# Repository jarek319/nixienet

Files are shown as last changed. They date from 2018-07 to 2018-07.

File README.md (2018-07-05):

# nixienet
Connecting 1960's tube tech to 2010's Wifi chips!

This Wifi gadget connects to time and weather forecast servers and uses Nixie tubes to display the current time and upcoming weather.

It's one of the most full designs I've ever made, from insides to outsides. So fun :)

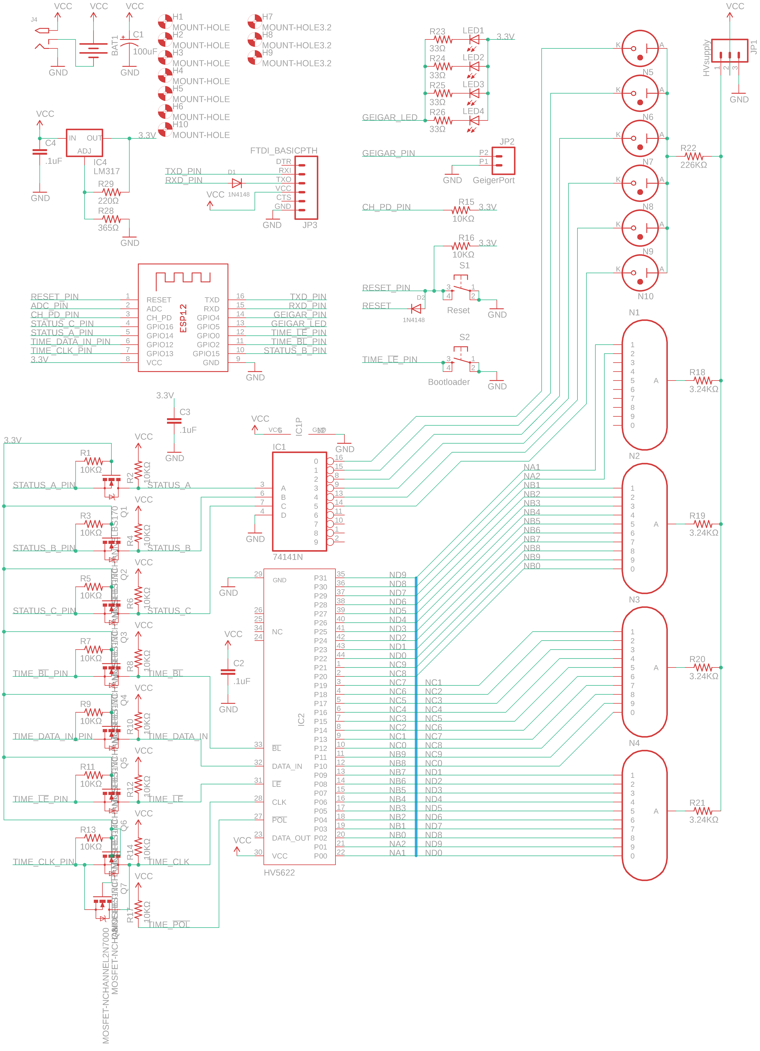
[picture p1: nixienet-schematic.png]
schematic

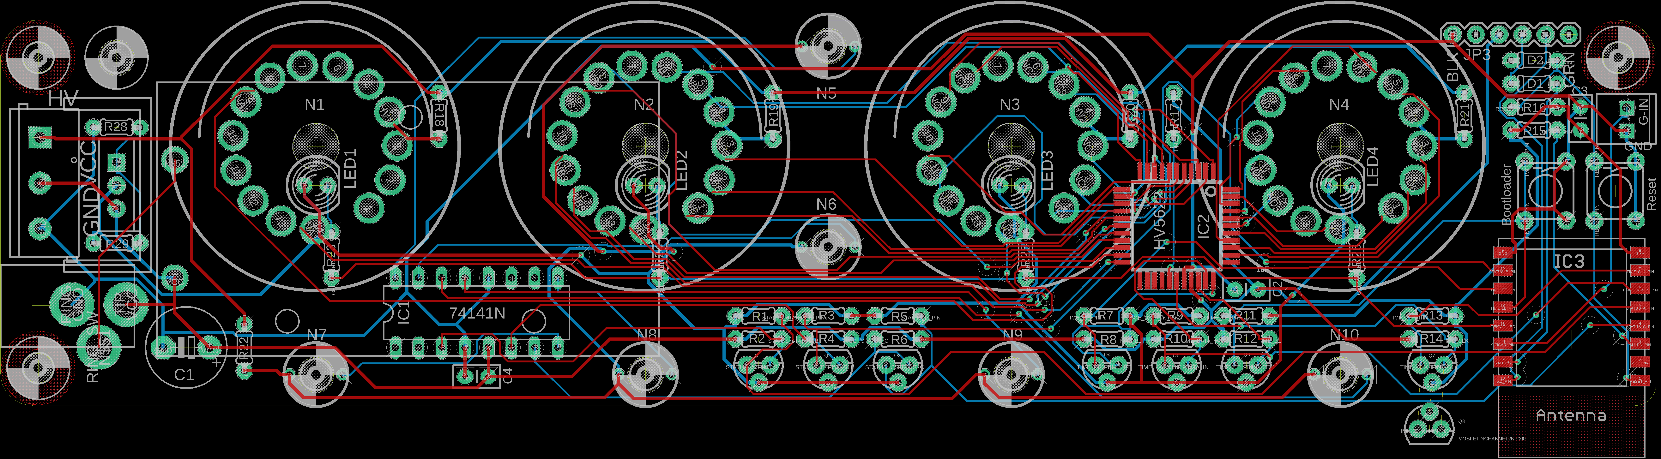
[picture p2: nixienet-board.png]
board

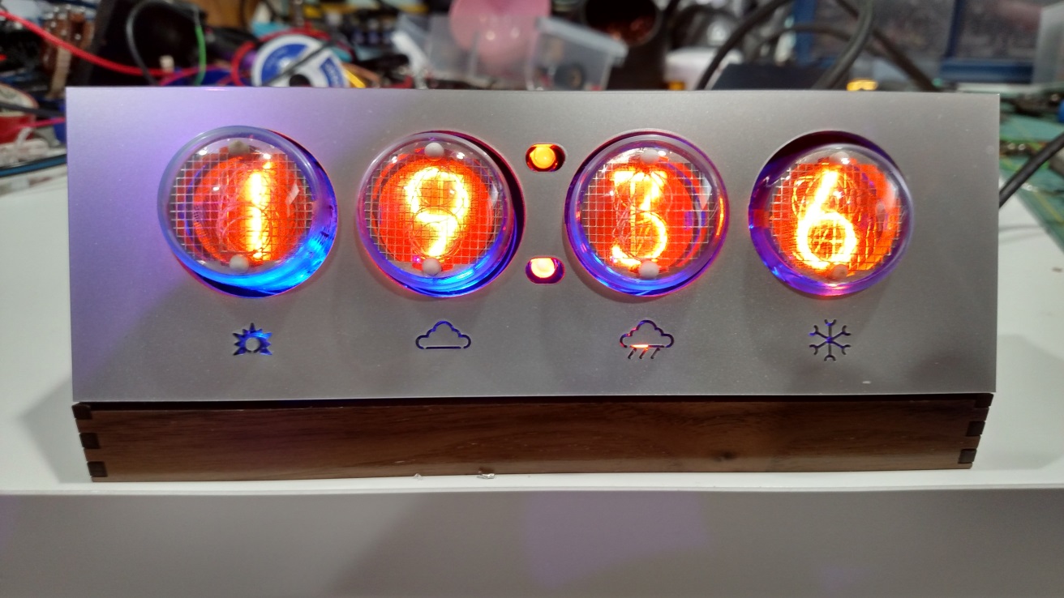
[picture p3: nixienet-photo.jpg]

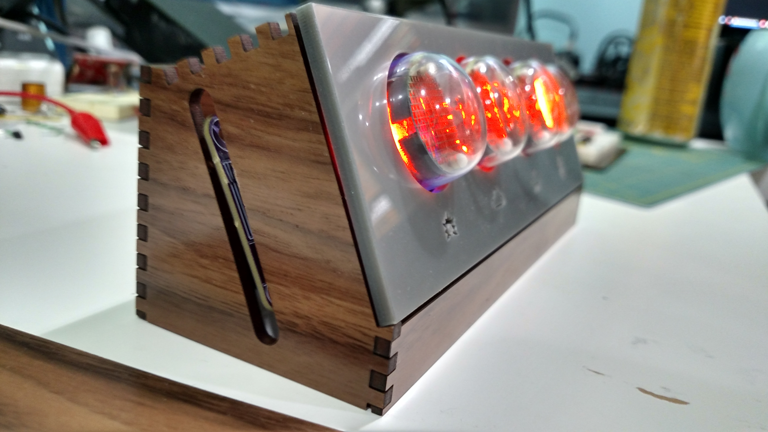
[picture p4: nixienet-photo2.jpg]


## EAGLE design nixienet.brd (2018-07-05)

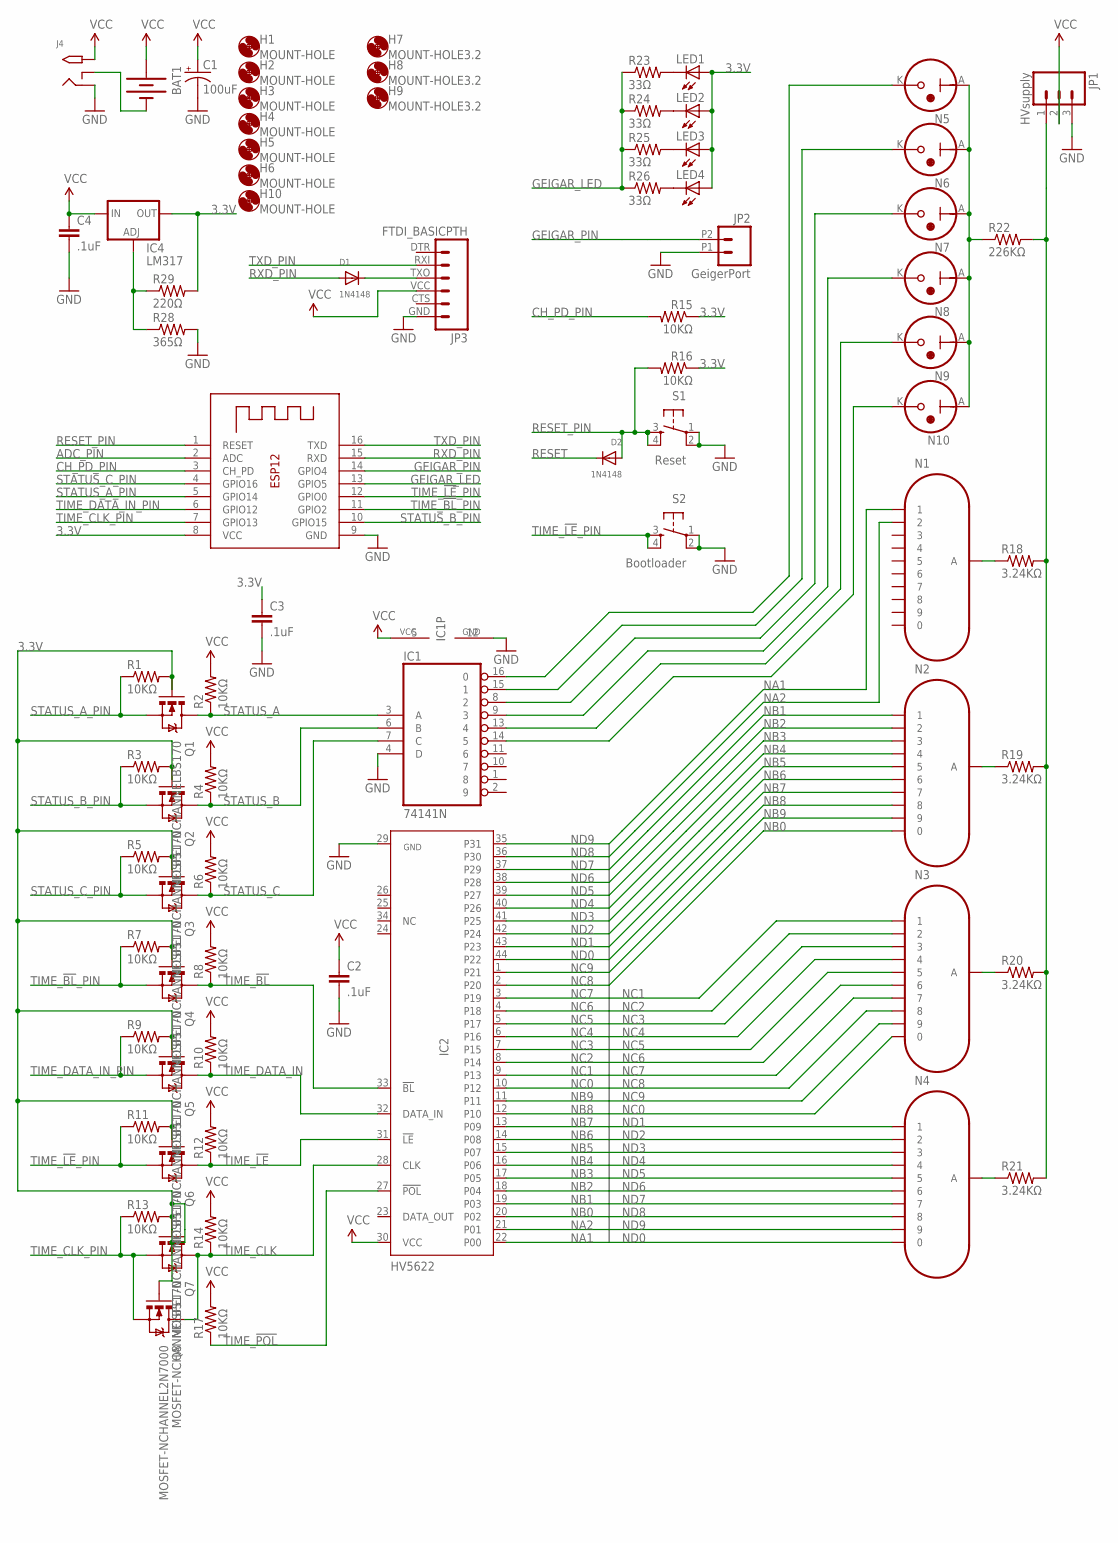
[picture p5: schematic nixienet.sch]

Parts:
BAT1: BATTERY9V; BATTCON_9V
C1: 100uF; E5-8,5
C2, C3, C4: .1uF; CAP-PTH-SMALLEZ
D1, D2: 1N4148
H1, H2, H3, H4, H5, H6, H10: MOUNT-HOLE; 3,2-DANGER
H7, H8, H9: MOUNT-HOLE3.2; 3,2
IC1: 74141N; DIL16
IC2: HV5622; QFP44
IC3: ESP-12
IC4: LM317; SPARKFUN-POWERIC_TO220-ADJ
J4: 2.1MMJACKTHM; PJ-102A
JP1: HVsupply; SCREWTERMINAL-5MM-3
JP2: GeigerPort; 1X02_2.54_SCREWTERM
JP3: FTDI_BASICPTH; FTDI_BASIC
LED1, LED2, LED3, LED4: LED5MM
N1: Hour1; IN-18
N2: Hour2; IN-18
N3: Minutes1; IN-18
N4: Minutes2; IN-18
N5: TopBulb; INS-1
N6: BottomBulb; INS-1
N7: SunnyBulb; INS-1
N8: CloudyBulb; INS-1
N9: RainyBulb; INS-1
N10: SnowyBulb; INS-1
Q1, Q2, Q3, Q4, Q5, Q6, Q7: MOSFET-NCHANNELBS170; TO-92
Q8: MOSFET-NCHANNEL2N7000; TO-92
R1, R2, R3, R4, R5, R6, R7, R8, R9, R10, R11, R12, R13, R14, R15, R16, R17: 10KΩ; 0204/5
R18, R19, R20, R21: 3.24KΩ; 0204/5
R22: 226KΩ; 0204/5
R23, R24, R25, R26: 33Ω; 0204/5
R28: 365Ω; 0204/5
R29: 220Ω; 0204/5
S1: Reset; TACTILE-PTH
S2: Bootloader; TACTILE-PTH

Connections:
3.3V: C3.1, IC3.8 (VCC), IC4.OUT, LED1.A, LED2.A, LED3.A, LED4.A, Q1.2 (G), Q2.2 (G), Q3.2 (G), Q4.2 (G), Q5.2 (G), Q6.2 (G), Q7.2 (G), Q8.2 (G), R1.2, R3.2, R5.2, R7.2, R9.2, R11.2, R13.2, R15.1, R16.1, R29.2
ADC_PIN: IC3.2 (ADC)
CH_PD_PIN: IC3.3 (CH_PD), R15.2
GEIGAR_LED: IC3.13 (GPIO5), R23.1, R24.1, R25.1, R26.1
GEIGAR_PIN: IC3.14 (GPIO4), JP2.P2 (2)
GND: C1.-, C2.2, C3.2, C4.2, IC1.4 (D), IC1.12 (GND), IC2.29 (GND), IC3.9 (GND), J4.RING, JP1.3, JP2.P1 (1), JP3.GND (6), R28.2, S1.1, S1.2, S2.1, S2.2
HV: JP1.1, R18.2, R19.2, R20.2, R21.2, R22.2
HV1: N1.4 (A), R18.1
HV2: N2.4 (A), R19.1
HV3: N3.4 (A), R20.1
HV4: N4.4 (A), R21.1
HVB: N5.A, N6.A, N7.A, N8.A, N9.A, N10.A, R22.1
unnamed: IC4.ADJ, R28.1, R29.1
unnamed: IC1.14 (5), N10.K
unnamed: IC1.13 (4), N9.K
unnamed: IC1.9 (3), N8.K
unnamed: IC1.8 (2), N7.K
unnamed: IC1.15 (1), N6.K
unnamed: IC1.16 (0), N5.K
unnamed: D1.K (C), JP3.TXO (3)
unnamed: BAT1.-, J4.RING_SW
unnamed: LED1.K (C), R23.2
unnamed: LED3.K (C), R25.2
unnamed: LED4.K (C), R26.2
unnamed: LED2.K (C), R24.2
NA1: IC2.22 (P00), N1.14 (1)
NA2: IC2.21 (P01), N1.9 (2)
NB0: IC2.20 (P02), N2.8 (0)
NB1: IC2.19 (P03), N2.14 (1)
NB2: IC2.18 (P04), N2.9 (2)
NB3: IC2.17 (P05), N2.11 (3)
NB4: IC2.16 (P06), N2.1 (4)
NB5: IC2.15 (P07), N2.12 (5)
NB6: IC2.14 (P08), N2.2 (6)
NB7: IC2.13 (P09), N2.6 (7)
NB8: IC2.12 (P10), N2.3 (8)
NB9: IC2.11, N2.5 (9)
NC0: IC2.10 (P12), N3.8 (0)
NC1: IC2.9 (P13), N3.14 (1)
NC2: IC2.8 (P14), N3.9 (2)
NC3: IC2.7 (P15), N3.11 (3)
NC4: IC2.6 (P16), N3.1 (4)
NC5: IC2.5 (P17), N3.12 (5)
NC6: IC2.4 (P18), N3.2 (6)
NC7: IC2.3 (P19), N3.6 (7)
NC8: IC2.2 (P20), N3.3 (8)
NC9: IC2.1 (P21), N3.5 (9)
ND0: IC2.44 (P22), N4.8 (0)
ND1: IC2.43 (P23), N4.14 (1)
ND2: IC2.42 (P24), N4.9 (2)
ND3: IC2.41 (P25), N4.11 (3)
ND4: IC2.40 (P26), N4.1 (4)
ND5: IC2.39 (P27), N4.12 (5)
ND6: IC2.38 (P28), N4.2 (6)
ND7: IC2.37 (P29), N4.6 (7)
ND8: IC2.36 (P30), N4.3 (8)
ND9: IC2.35 (P31), N4.5 (9)
RESET: D2.K (C)
RESET_PIN: D2.A, IC3.1 (RESET), R16.2, S1.3, S1.4
RXD_PIN: D1.A, IC3.15 (RXD)
STATUS_A: IC1.3 (A), Q1.1 (D), R2.1
STATUS_A_PIN: IC3.5 (GPIO14), Q1.3 (S), R1.1
STATUS_B: IC1.6 (B), Q2.1 (D), R4.1
STATUS_B_PIN: IC3.10 (GPIO15), Q2.3 (S), R3.1
STATUS_C: IC1.7 (C), Q3.1 (D), R6.1
STATUS_C_PIN: IC3.4 (GPIO16), Q3.3 (S), R5.1
TIME_!BL: IC2.33 (!BL), Q4.1 (D), R8.1
TIME_!BL!_PIN: IC3.11 (GPIO2), Q4.3 (S), R7.1
TIME_!LE: IC2.31 (!LE!), Q6.1 (D), R12.1
TIME_!LE!_PIN: IC3.12 (GPIO0), Q6.3 (S), R11.1, S2.3, S2.4
TIME_!POL: IC2.27 (!POL!), R17.1
TIME_CLK: IC2.28 (CLK), Q7.1 (D), Q8.3 (D), R14.1
TIME_CLK_PIN: IC3.7 (GPIO13), Q7.3 (S), Q8.1 (S), R13.1
TIME_DATA_IN: IC2.32 (DATA_IN), Q5.1 (D), R10.1
TIME_DATA_IN_PIN: IC3.6 (GPIO12), Q5.3 (S), R9.1
TXD_PIN: IC3.16 (TXD), JP3.RXI (2)
VCC: BAT1.+, C1.+, C2.1, C4.1, IC1.5 (VCC), IC2.30 (VCC), IC4.IN, J4.TIP, JP1.2, JP3.VCC (4), R2.2, R4.2, R6.2, R8.2, R10.2, R12.2, R14.2, R17.2

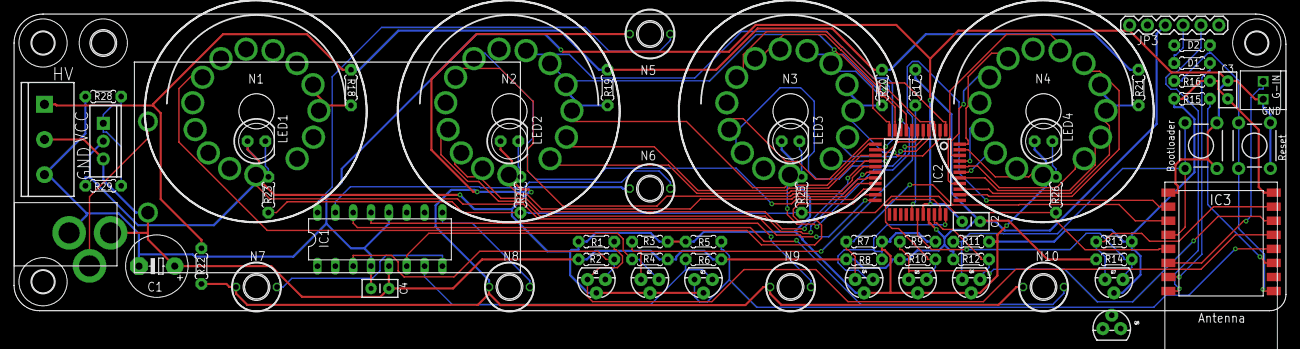
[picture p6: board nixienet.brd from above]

Board: 2 copper layers, 181.0 x 42.2 mm, 77 parts (0 on the bottom side), 75 nets.

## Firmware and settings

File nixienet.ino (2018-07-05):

#include <Time.h>
#include <ESP8266WiFi.h>
#include <WiFiUdp.h>

const byte sinArray[60] = {83, 101, 119, 136, 153, 169, 184, 198, 211, 222, 232, 240, 247, 251, 254, 255, 254, 251, 247, 240, 232, 222, 211, 198, 184, 169, 153, 136, 119, 101, 83, 65, 47, 30, 13, 0, 0, 0, 0, 0, 0, 0, 0, 0, 0, 0, 0, 0, 0, 0, 0, 0, 0, 0, 0, 0, 13, 30, 47, 65};
const int timeZone = -4;  // Eastern Standard Time (USA)

int nixieBulbDelayTime = 500;
int ledFadeTime = 8;

String ZIPCODE = "*";
String APPID = "*";

char ssid[] = "*";
char pass[] = "*";
char host[] = "api.openweathermap.org";

int GEIGER_PIN = 5;
int GEIGER_LED = 4;
int TIME_DATA_IN_PIN = 12;
int TIME_CLK_PIN = 13;
int TIME_LE_PIN = 0;
int TIME_BL_PIN = 2;
int STATUS_A_PIN = 14;
int STATUS_B_PIN = 15;
int STATUS_C_PIN = 16;

struct nixieStruct {
  byte hour1;
  byte hour2;
  byte minute1;
  byte minute2;
  byte bulbs;
};

time_t prevDisplay = 0; // when the digital clock was displayed

nixieStruct nixies = {2, 9, 9, 9, 15}; // initialize nixie tubes

unsigned int localPort = 2390;        // local port to listen for UDP packets
IPAddress timeServer(129, 6, 15, 28); // time.nist.gov NTP server
const int NTP_PACKET_SIZE = 48;       // NTP time stamp is in the first 48 bytes of the message
byte packetBuffer[NTP_PACKET_SIZE];   // buffer to hold incoming and outgoing packets
WiFiUDP udp;

void drawNixies() {
  if (now() != prevDisplay) { //update the display only if time has changed
    prevDisplay = now();
    nixies.hour1 = hour() / 10;
    nixies.hour2 = hour() % 10;
    nixies.minute1 = minute() / 10;
    nixies.minute2 = minute() % 10;
  }

  int c = 0;                            //initialize counter
  digitalWrite(TIME_LE_PIN, LOW);       //open shift register latch
  digitalWrite(TIME_DATA_IN_PIN, LOW);  //set next bit low
  for (c = 0; c < 32; c++) {            //push low bit 32 times to clear the register
    digitalWrite(TIME_CLK_PIN, HIGH);
    digitalWrite(TIME_CLK_PIN, LOW);
  }
  digitalWrite(TIME_LE_PIN, HIGH);      //push latch
  digitalWrite(TIME_LE_PIN, LOW);       //open latch
  digitalWrite(TIME_DATA_IN_PIN, LOW);  //set next bit low
  for (c = 9; c > nixies.minute2; c--) {
    digitalWrite(TIME_CLK_PIN, HIGH);
    digitalWrite(TIME_CLK_PIN, LOW);
  }
  digitalWrite(TIME_DATA_IN_PIN, HIGH);
  digitalWrite(TIME_CLK_PIN, HIGH);
  digitalWrite(TIME_CLK_PIN, LOW);
  digitalWrite(TIME_DATA_IN_PIN, LOW);
  for (c; c > 0; c--) {
    digitalWrite(TIME_CLK_PIN, HIGH);
    digitalWrite(TIME_CLK_PIN, LOW);
  }
  digitalWrite(TIME_DATA_IN_PIN, LOW);
  for (c = 9; c > nixies.minute1; c--) {
    digitalWrite(TIME_CLK_PIN, HIGH);
    digitalWrite(TIME_CLK_PIN, LOW);
  }
  digitalWrite(TIME_DATA_IN_PIN, HIGH);
  digitalWrite(TIME_CLK_PIN, HIGH);
  digitalWrite(TIME_CLK_PIN, LOW);
  digitalWrite(TIME_DATA_IN_PIN, LOW);
  for (c; c > 0; c--) {
    digitalWrite(TIME_CLK_PIN, HIGH);
    digitalWrite(TIME_CLK_PIN, LOW);
  }
  digitalWrite(TIME_DATA_IN_PIN, LOW);
  for (c = 9; c > nixies.hour2; c--) {
    digitalWrite(TIME_CLK_PIN, HIGH);
    digitalWrite(TIME_CLK_PIN, LOW);
  }
  digitalWrite(TIME_DATA_IN_PIN, HIGH);
  digitalWrite(TIME_CLK_PIN, HIGH);
  digitalWrite(TIME_CLK_PIN, LOW);
  digitalWrite(TIME_DATA_IN_PIN, LOW);
  for (c; c > 0; c--) {
    digitalWrite(TIME_CLK_PIN, HIGH);
    digitalWrite(TIME_CLK_PIN, LOW);
  }
  digitalWrite(TIME_DATA_IN_PIN, LOW);
  if (nixies.hour1 != 0) {
    for (c = 2; c > nixies.hour1; c--) {
      digitalWrite(TIME_CLK_PIN, HIGH);
      digitalWrite(TIME_CLK_PIN, LOW);
    }
    digitalWrite(TIME_DATA_IN_PIN, HIGH);
    digitalWrite(TIME_CLK_PIN, HIGH);
    digitalWrite(TIME_CLK_PIN, LOW);
    digitalWrite(TIME_DATA_IN_PIN, LOW);
    for (c; c > 1; c--) {
      digitalWrite(TIME_CLK_PIN, HIGH);
      digitalWrite(TIME_CLK_PIN, LOW);
    }
  }
  else {
    for (int i = 0; i < 2; i++) {
      digitalWrite(TIME_CLK_PIN, HIGH);
      digitalWrite(TIME_CLK_PIN, LOW);
    }
  }
  digitalWrite(TIME_LE_PIN, HIGH);

  if (nixies.bulbs & 0x01) { // Top Colon
    digitalWrite(STATUS_A_PIN, LOW);
    digitalWrite(STATUS_B_PIN, LOW);
    digitalWrite(STATUS_C_PIN, LOW);
    delayMicroseconds(nixieBulbDelayTime);
  }
  if (nixies.bulbs & 0x02) { // Botton Colon
    digitalWrite(STATUS_A_PIN, HIGH);
    digitalWrite(STATUS_B_PIN, LOW);
    digitalWrite(STATUS_C_PIN, LOW);
    delayMicroseconds(nixieBulbDelayTime);
  }
  if (nixies.bulbs & 0x04) { // Sun
    digitalWrite(STATUS_A_PIN, LOW);
    digitalWrite(STATUS_B_PIN, HIGH);
    digitalWrite(STATUS_C_PIN, HIGH);
    delayMicroseconds(nixieBulbDelayTime);
  }
  if (nixies.bulbs & 0x08) { // Cloud
    digitalWrite(STATUS_A_PIN, LOW);
    digitalWrite(STATUS_B_PIN, HIGH);
    digitalWrite(STATUS_C_PIN, LOW);
    delayMicroseconds(nixieBulbDelayTime);
  }
  if (nixies.bulbs & 0x10) { // Rain
    digitalWrite(STATUS_A_PIN, LOW);
    digitalWrite(STATUS_B_PIN, LOW);
    digitalWrite(STATUS_C_PIN, HIGH);
    delayMicroseconds(nixieBulbDelayTime);
  }
  if (nixies.bulbs & 0x20) { // Snow
    digitalWrite(STATUS_A_PIN, HIGH);
    digitalWrite(STATUS_B_PIN, LOW);
    digitalWrite(STATUS_C_PIN, HIGH);
    delayMicroseconds(nixieBulbDelayTime);
  }
}

time_t getNtpTime() {
  WiFiClient client;
  const int httpPort = 80;
  if (!client.connect(host, httpPort)) {
    Serial.println("connection failed");
  }
  String url = "/data/2.5/forecast?zip=";
  url += ZIPCODE;
  url += ",us&APPID=";
  url += APPID;
  url += "&cnt=3";

  Serial.print("Requesting URL: ");
  Serial.println(url);

  // This will send the request to the server
  client.print(String("GET ") + url + " HTTP/1.1\r\n" +
               "Host: " + host + "\r\n" +
               "Connection: close\r\n\r\n");
  delay(1000);

  // Read all the lines of the reply from server and print them to Serial
  while (client.available()) {
    String storedRequestString = client.readStringUntil('\r');
    if (storedRequestString.charAt(1) == '{') {
      storedRequestString.remove(0, 1);
      storedRequestString.remove(storedRequestString.length() - 1);
      Serial.print("String: ");
      Serial.println(storedRequestString);
      int index1 = storedRequestString.indexOf("\"dt\":");
      int index2 = storedRequestString.indexOf("\"dt\":", index1 + 1);
      int index3 = storedRequestString.indexOf("\"dt\":", index2 + 1);
      int weatherIndex1 = storedRequestString.indexOf("\"weather\":[{\"id\":", index1);
      int weatherIndex2 = storedRequestString.indexOf("\"weather\":[{\"id\":", index2);
      int weatherIndex3 = storedRequestString.indexOf("\"weather\":[{\"id\":", index3);
      String forecastString1 = storedRequestString.substring(weatherIndex1 + 17, weatherIndex1 + 20);
      String forecastString2 = storedRequestString.substring(weatherIndex2 + 17, weatherIndex2 + 20);
      String forecastString3 = storedRequestString.substring(weatherIndex3 + 17, weatherIndex3 + 20);
      Serial.println(forecastString1);
      Serial.println(forecastString2);
      Serial.println(forecastString3);
      nixies.bulbs &= 3;
      if (forecastString1.charAt(0) == '6' || forecastString2.charAt(0) == '6' || forecastString3.charAt(0) == '6') {
        nixies.bulbs |= 0x20; //SNOW
        Serial.println("Snow");
      }
      else if (forecastString1.charAt(0) == '5' || forecastString2.charAt(0) == '5' || forecastString3.charAt(0) == '5' || forecastString1.charAt(0) == '3' || forecastString2.charAt(0) == '3' || forecastString3.charAt(0) == '3' || forecastString1.charAt(0) == '2' || forecastString2.charAt(0) == '2' || forecastString3.charAt(0) == '2') {
        nixies.bulbs |= 0x10; //RAIN
        Serial.println("Rain");
      }
      else if ((forecastString1.charAt(0) == '8' || forecastString2.charAt(0) == '8' || forecastString3.charAt(0) == '8') && (forecastString1.charAt(2) != '0' || forecastString2.charAt(2) != '0' || forecastString3.charAt(2) != '0')) {
        nixies.bulbs |= 0x08; //CLOUDS
        Serial.println("Clouds");
      }
      else {
        nixies.bulbs |= 0x04; //CLEAR
        Serial.println("Clear");
      }

      Serial.println(forecastString1);
      Serial.println(forecastString2);
      Serial.println(forecastString3);
      /*
      const char* sensor = root["coord"];
      const char* time = root["weather"];
      Serial.println(sensor);
      Serial.println(time);
      */
    }
  }
  Serial.println();
  Serial.println("closing connection");

  while (udp.parsePacket() > 0) ; // discard any previously received packets
  Serial.println("Transmit NTP Request");
  sendNTPpacket(timeServer);
  uint32_t beginWait = millis();
  while (millis() - beginWait < 1500) {
    if (!udp.parsePacket()) {}
    else {
      Serial.println("Receive NTP Response");
      udp.read(packetBuffer, NTP_PACKET_SIZE);  // read packet into the buffer
      unsigned long secsSince1900;
      // convert four bytes starting at location 40 to a long integer
      secsSince1900 =  (unsigned long)packetBuffer[40] << 24;
      secsSince1900 |= (unsigned long)packetBuffer[41] << 16;
      secsSince1900 |= (unsigned long)packetBuffer[42] << 8;
      secsSince1900 |= (unsigned long)packetBuffer[43];
      return secsSince1900 - 2208988800UL + timeZone * SECS_PER_HOUR;
    }
  }
  Serial.println("No NTP Response :-(");
  return 0; // return 0 if unable to get the time
}

void setup() {
  pinMode(GEIGER_PIN, INPUT);
  pinMode(GEIGER_LED, OUTPUT);
  digitalWrite(GEIGER_LED, LOW);
  pinMode(TIME_DATA_IN_PIN, OUTPUT);
  digitalWrite(TIME_DATA_IN_PIN, LOW);
  pinMode(TIME_CLK_PIN, OUTPUT);
  digitalWrite(TIME_CLK_PIN, LOW);
  pinMode(TIME_LE_PIN, OUTPUT);
  digitalWrite(TIME_LE_PIN, HIGH);
  pinMode(TIME_BL_PIN, OUTPUT);
  digitalWrite(TIME_BL_PIN, HIGH);
  pinMode(STATUS_A_PIN, OUTPUT);
  digitalWrite(STATUS_A_PIN, HIGH);
  pinMode(STATUS_B_PIN, OUTPUT);
  digitalWrite(STATUS_B_PIN, HIGH);
  pinMode(STATUS_C_PIN, OUTPUT);
  digitalWrite(STATUS_C_PIN, HIGH);
  drawNixies();

  Serial.begin(115200);

  // We start by connecting to a WiFi network
  Serial.print("Connecting to ");
  Serial.println(ssid);
  WiFi.begin(ssid, pass);

  while (WiFi.status() != WL_CONNECTED) {
    delay(500);
    Serial.print(".");
  }
  Serial.println("");

  Serial.println("WiFi connected");
  Serial.println("IP address: ");
  Serial.println(WiFi.localIP());

  Serial.println("Starting UDP");
  udp.begin(localPort);
  Serial.print("Local port: ");
  Serial.println(udp.localPort());

  setSyncProvider(getNtpTime);
}

void loop() {
  analogWrite(GEIGER_LED, constrain((sin((((millis() / ledFadeTime) % 1024) - 0) * (6.28 - 0.00) / (1024 - 0) + 0.00) + 1.00) * 512.00, 5, 1015));
  drawNixies();
}

unsigned long sendNTPpacket(IPAddress& address) { // send an NTP request to the time server at the given address
  Serial.println("sending NTP packet...");
  // set all bytes in the buffer to 0
  memset(packetBuffer, 0, NTP_PACKET_SIZE);
  // Initialize values needed to form NTP request
  // (see URL above for details on the packets)
  packetBuffer[0] = 0b11100011;   // LI, Version, Mode
  packetBuffer[1] = 0;     // Stratum, or type of clock
  packetBuffer[2] = 6;     // Polling Interval
  packetBuffer[3] = 0xEC;  // Peer Clock Precision
  // 8 bytes of zero for Root Delay & Root Dispersion
  packetBuffer[12]  = 49;
  //  packetBuffer[13]  = 0x4E;
  packetBuffer[14]  = 49;
  packetBuffer[15]  = 52;

  // all NTP fields have been given values, now
  // you can send a packet requesting a timestamp:
  udp.beginPacket(address, 123); //NTP requests are to port 123
  udp.write(packetBuffer, NTP_PACKET_SIZE);
  udp.endPacket();
}

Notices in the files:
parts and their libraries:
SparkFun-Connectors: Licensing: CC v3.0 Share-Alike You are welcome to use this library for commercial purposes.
